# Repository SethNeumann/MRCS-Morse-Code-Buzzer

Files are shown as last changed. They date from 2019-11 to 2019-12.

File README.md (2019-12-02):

# MRCS-Morse-Code-Buzzer
## License: Creative Commons Attribution-NonCommercial-ShareAlike

On many operations-oriented model railroads, particularly those
which a time-table and train-order (TT&TO) or tower-based dispatching
system, there is a need to provide telephone communications between
the dispatcher and the agent/operators. However, even on fairly
large model railroads with multiple agent/operators, the physical
distances between the operator positions are often insufficient to
allow the operators to reliably distinguish that “hey that’s my
phone ringing.”

The Morse Code Buzzer Controller board controls up to seven stations,
tapping out each ringing station's Telegraph code in Railroad Morse.
An additional output can be designated an “ambience” buzzer that
will randomly play one of several canned messages. These could be
train orders, news reports, or “inside jokes”

The board accepts a push button input, stops when the phone goes
off-hook (phone must have a suitable contact to provide an isolated
ground) and will drive loads of up to 0.5 Amp at up to 48 Volts DC.
All buzzer/sounder devices must use the same supply.  Sounders must
have have a coil resistance of greater than 40 ohms if using a 12V
supply.

Requires a 6-9 VDC power supply rated at at least 0.5A. not included.

The on-board Arduino Pro-Mini runs the
["station buzzers" sketch](https://github.com/stevew1154/station_buzzers)
by Steve Williams.

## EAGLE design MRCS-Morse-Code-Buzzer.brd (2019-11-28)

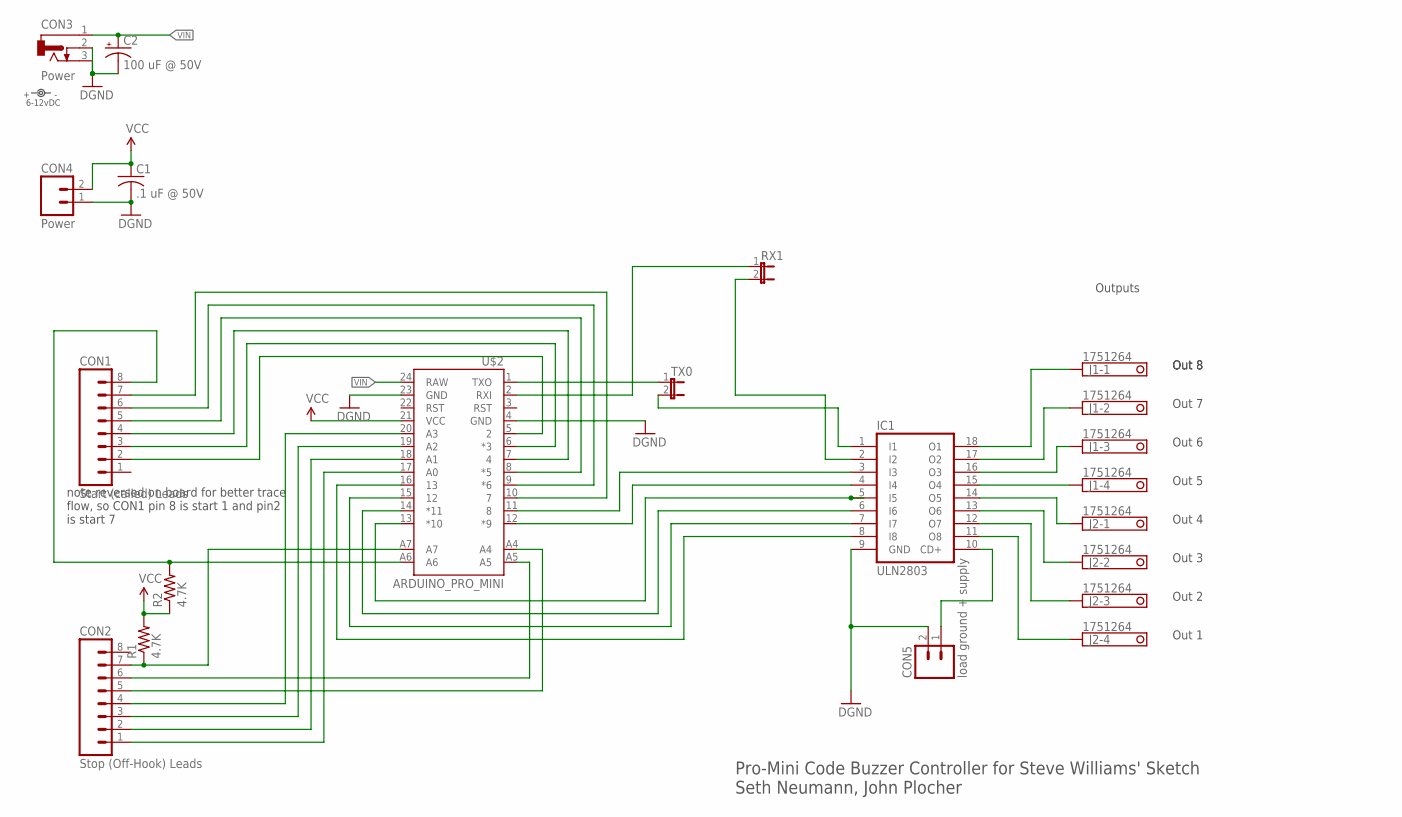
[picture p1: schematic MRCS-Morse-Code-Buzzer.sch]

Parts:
C1: .1 uF @ 50V; C025-030X050
C2: 100 uF @ 50V; E3.5-10
CON1: Start (called) Leads; 1X08_LOCK
CON2: Stop (Off-Hook) Leads; 1X08_LOCK
CON3: Power; DCJ0202
CON4: Power; MSTB2
CON5: load ground + supply; MSTB2
IC1: ULN2803; DIL18
J1, J2: 1751264
R1, R2: 4.7K; AXIAL-0.4-RES
RX1: JUMPER-2PTH; 1X02
TX0: JUMPER-2PTH; 1X02
U$2: ARDUINO_PRO_MINI
U$4: 6-12vDC; PWR_LABEL

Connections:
GND: C1.2, C2.-, CON3.2, CON3.3, CON4.1 (A), CON5.2 (B), IC1.9 (GND), U$2.4 (GND), U$2.23 (GND)
unnamed: IC1.18 (O1), J1.1
unnamed: IC1.17 (O2), J1.2
unnamed: IC1.16 (O3), J1.3
unnamed: IC1.15 (O4), J1.4
unnamed: IC1.14 (O5), J2.1
unnamed: IC1.13 (O6), J2.2
unnamed: IC1.12 (O7), J2.3
unnamed: IC1.11 (O8), J2.4
unnamed: CON1.2, U$2.5 (2)
unnamed: CON1.3, U$2.6 (*3)
unnamed: CON1.4, U$2.7 (4)
unnamed: CON1.5, U$2.8 (*5)
unnamed: CON1.6, U$2.9 (*6)
unnamed: CON1.7, U$2.10 (7)
unnamed: CON1.8, R2.P$2 (2), U$2.A6
unnamed: CON2.7, R1.P$1 (1), U$2.A7
unnamed: CON2.1, U$2.17 (A0)
unnamed: IC1.3 (I3), U$2.11 (8)
unnamed: IC1.4 (I4), U$2.12 (*9)
unnamed: IC1.8 (I8), U$2.16 (13)
unnamed: IC1.5 (I5), U$2.13 (*10)
unnamed: IC1.6 (I6), U$2.14 (*11)
unnamed: IC1.7 (I7), U$2.15 (12)
unnamed: CON2.2, U$2.18 (A1)
unnamed: CON2.3, U$2.19 (A2)
unnamed: CON2.4, U$2.20 (A3)
unnamed: CON2.5, U$2.A4
unnamed: CON2.6, U$2.A5
unnamed: TX0.1, U$2.1 (TXO)
unnamed: IC1.1 (I1), TX0.2
unnamed: IC1.2 (I2), RX1.2
unnamed: CON5.1 (A), IC1.10 (CD+)
unnamed: RX1.1, U$2.2 (RXI)
VCC: C1.1, CON4.2 (B), R1.P$2 (2), R2.P$1 (1), U$2.21 (VCC)
VIN: C2.+, CON3.1, U$2.24 (RAW)

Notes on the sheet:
Pro-Mini Code Buzzer Controller for Steve Williams' Sketch Seth Neumann, John Plocher
Outputs
Out 8
Out 7
Out 6
Out 5
Out 4
Out 3
Out 2
Out 1
note reversed on board for better trace flow, so CON1 pin 8 is start 1 and pin2 is start 7

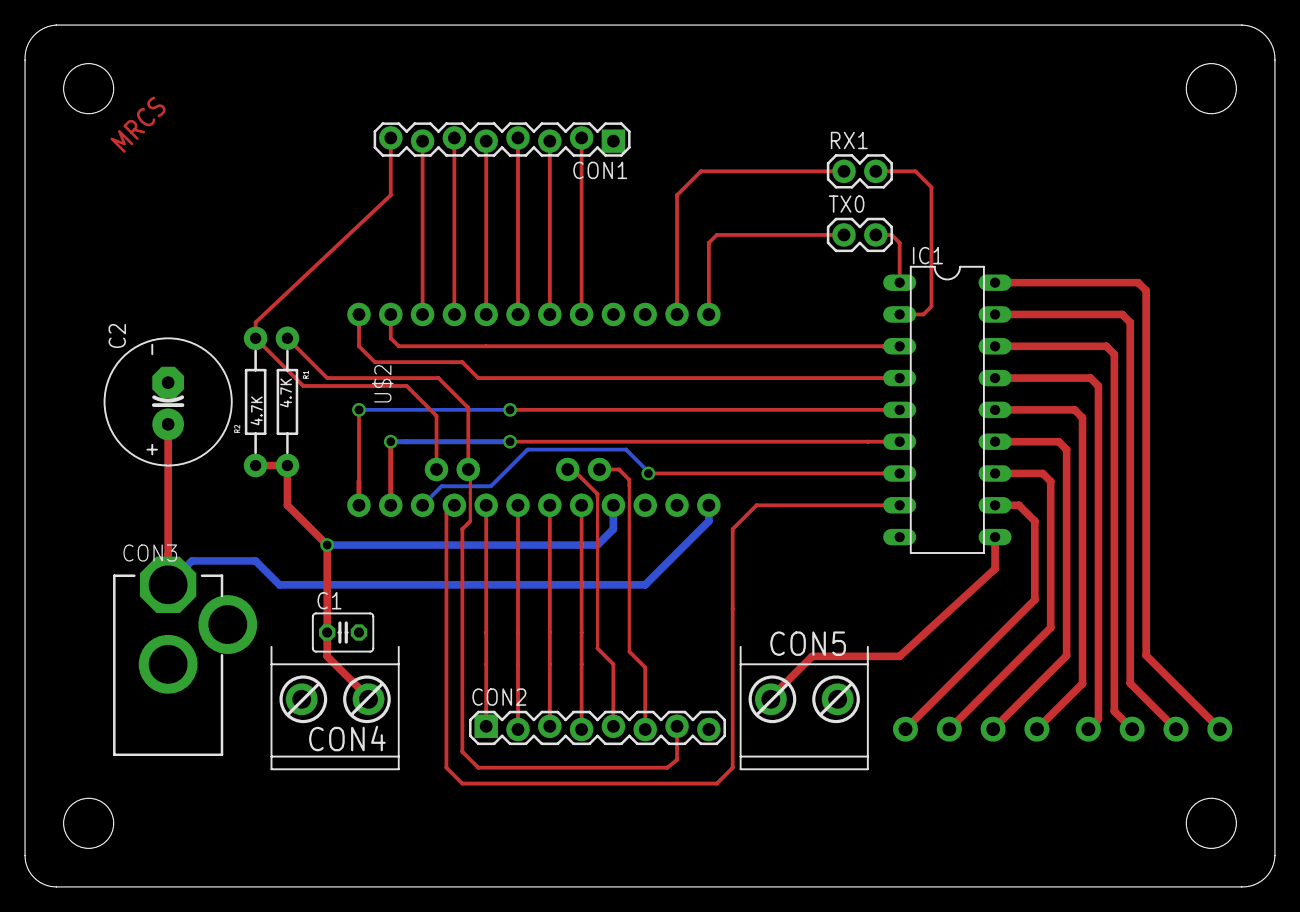
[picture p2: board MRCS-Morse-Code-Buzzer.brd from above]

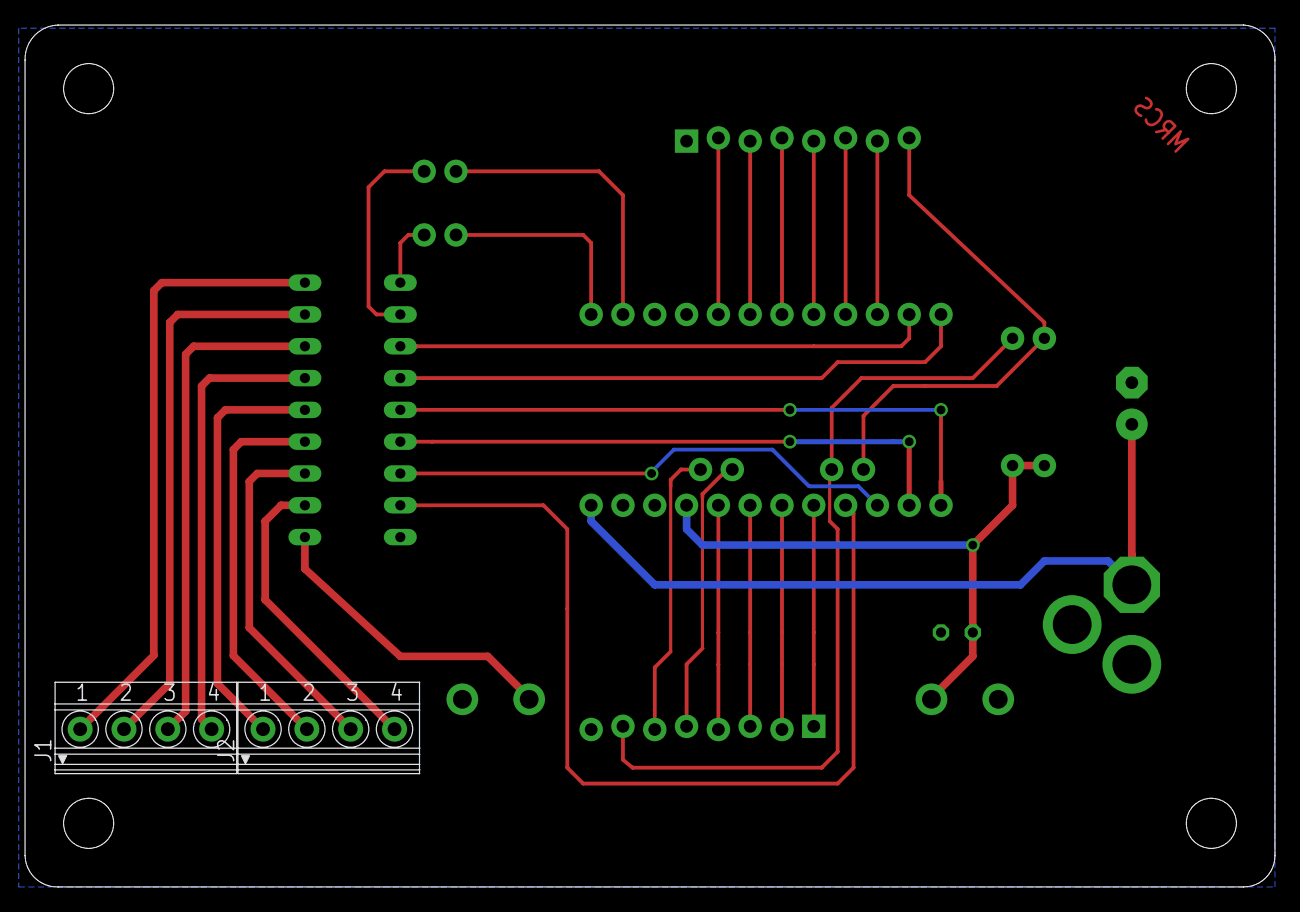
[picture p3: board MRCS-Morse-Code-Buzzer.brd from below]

Board: 2 copper layers, 99.8 x 68.8 mm, 18 parts (2 on the bottom side), 36 nets.

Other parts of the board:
U$1: BOARD-DINRAIL-2.71IN-MRCS
U$3: CA-PROP65-BACK

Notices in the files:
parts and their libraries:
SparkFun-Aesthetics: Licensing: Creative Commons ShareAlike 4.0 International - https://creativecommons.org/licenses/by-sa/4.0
